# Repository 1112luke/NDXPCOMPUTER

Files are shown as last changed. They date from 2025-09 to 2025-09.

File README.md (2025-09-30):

<h1 align="center">⚡️🚀Notre Dame Rocketry Flight Computer🖥️⚡️</h1>

<h2 align="center">F.E.R.B (For Every Rocketry Build) 🤓</h2>

<p align="center">
  
</p>

<h4 align="center">This is the repository for the HARDWARE DESIGN ONLY. Software for the computer can be found <a href="https://github.com/1112luke/NDXP_COMPUTER_SOFTWARE">here</a></h4>

<p align="center">
  
  
</p>

## Introduction

While initially designed and developed for NDXP, all vehicle applications were heavily considered during the process. The result is a computer that is <i>intended</i> to be used for any and all rocketry vehicles!

## Contributing
This repository is open at all times to any member submitting a Pull Request and merging their code directly into the main branch after approval! If you don't know what a Pull Request is, or if this is your first time using github, it is recommended that you watch [this](https://docs.github.com/en/get-started/start-your-journey/hello-world) guide before you begin.

### Requirements
Before you do anything, make sure you:
 - Have [git](https://git-scm.com/downloads) installed on your computer (macos should by default).
 - Have [kicad](https://www.kicad.org/) installed on your computer
 - Are added as a repository contributor (ask a team lead)

To make a contribution, the generall process is:

<b><i>clone/pull → branch → make your changes → add;commit;push → request approval for merge</i></b>

Each step is broken down as follows:

### Clone/Pull 🤖
If this is your first time interacting with this repository on your local machine, execute the following command in the location on your computer you wish to clone the repository to:

```
git clone https://github.com/1112luke/CubeFlightComputer
```

If you have the repository already and wish to begin a new contribution <b><u>it is important that you get the most recent version of the repository: </u></b>

```
git switch main
git pull origin main --rebase
```

### Branch 🪾
Once you have an up to date copy of the repository on your local machine, you will need to create a new branch for your contribution:

```
git branch -c branch-name
```

```
git switch branch-name
```

Feel free to name it whatever you want. Be descriptive!

### Make Your Changes 👨‍💻
At this point, you are free to make whatever changes you want! Any time you are working in your local copy, you do not have to worry about messing up the project. Feel free to delete the entire thing if you want!
 - Experiment
 - Break Things
 - Absolutely Cook 👨‍🍳

<b>THIS IS HOW WE LEARN!!</b>

### Add;Commit;Push 💡
When you are satisfied with your contribution, execute the following steps to push your changes to github for review:

```
git add .
```

```
git commit -m "your-descriptive-message"
```

```
git push origin branch-name
```

Once that is done, your code should be pushed to this repository! The final step is to submit a pull request for your code to the main branch using this website, and it will be reviewed for merge shortly!

### RULE OF THUMB!!
In general, commits to github should be <b>small</b> and <b>frequent</b>! This ensures that everybody is working with the most up to date version of the code!

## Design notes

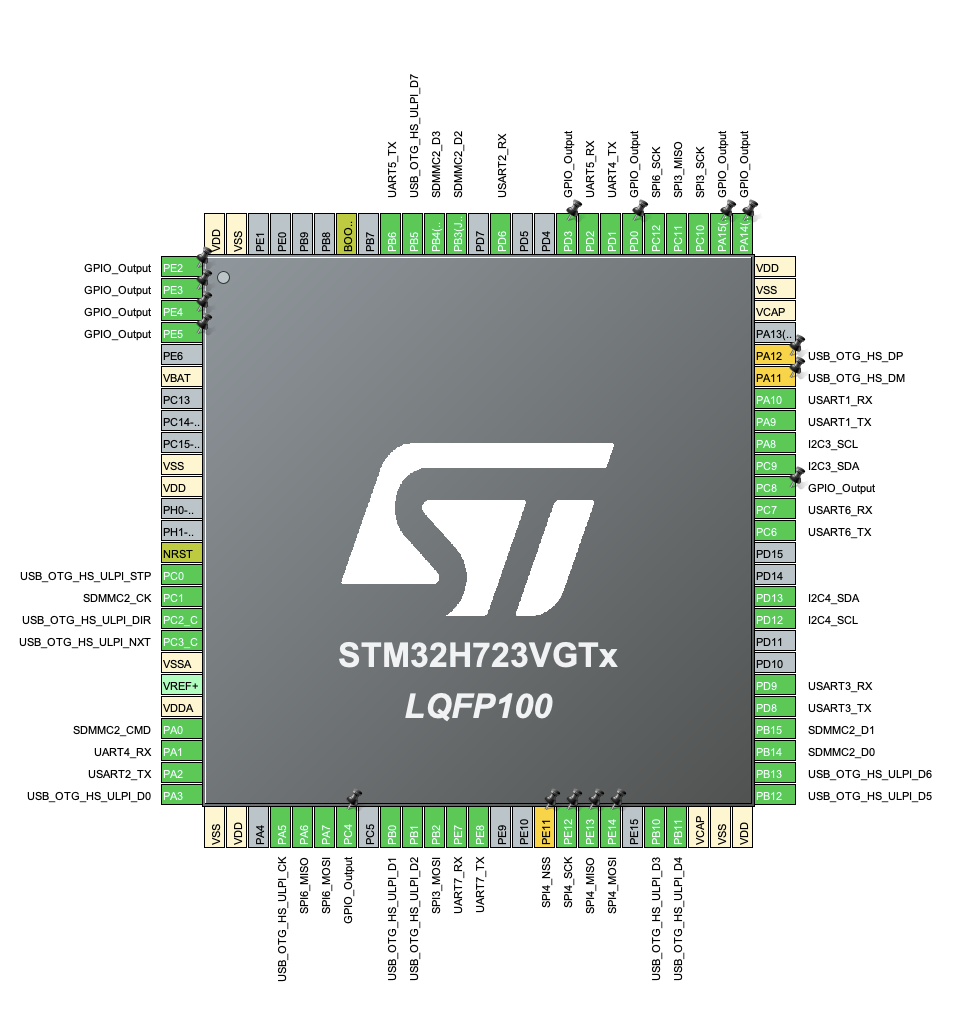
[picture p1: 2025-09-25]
Compute-Comms/Images/Screenshot 2025-09-24 at 10.30.06 PM.png

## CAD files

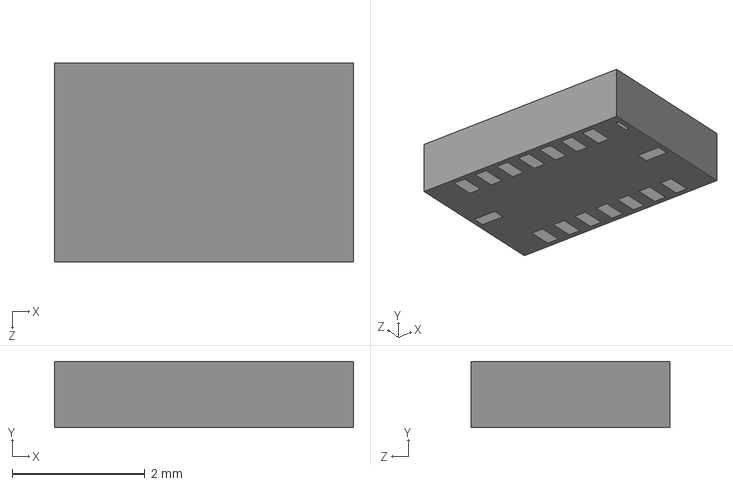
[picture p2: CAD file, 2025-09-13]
Compute-Comms/Custom_Parts/BMI088/BMI088.step
4.50 x 1.00 x 3.00 mm

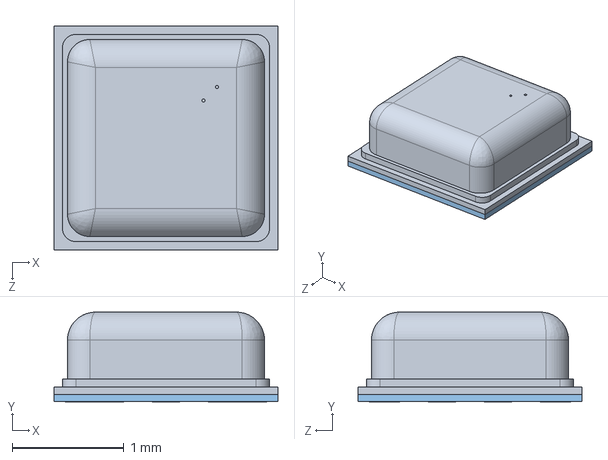
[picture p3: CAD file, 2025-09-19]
Compute-Comms/Custom_Parts/BMP581/BMP581.step
2.00 x 0.801 x 2.00 mm

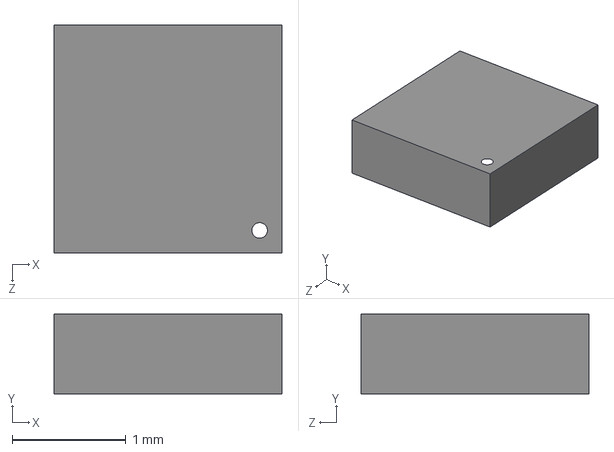
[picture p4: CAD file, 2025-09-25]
Compute-Comms/Custom_Parts/IIS2MDCTR/IIS2MDCTR.step
2.00 x 0.7 x 2.00 mm

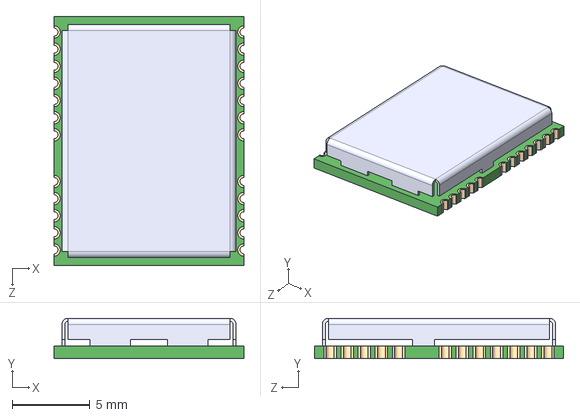
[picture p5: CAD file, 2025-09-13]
Compute-Comms/Custom_Parts/NEO-M9N/NEO-M9N-00B.step
12.2 x 2.60 x 16.0 mm

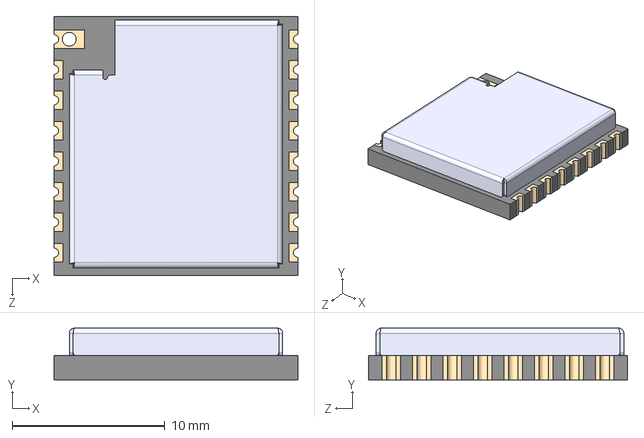
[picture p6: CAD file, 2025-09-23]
Compute-Comms/Custom_Parts/RA-01/RA-01H--3DModel-STEP-1.STEP
16.0 x 3.40 x 17.0 mm

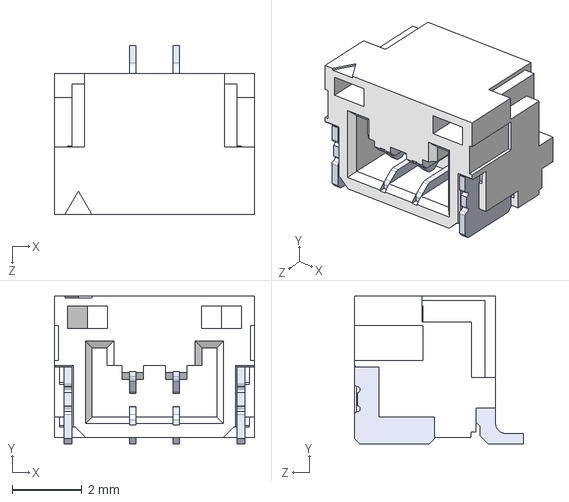
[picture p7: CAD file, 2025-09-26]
Compute-Comms/Custom_Parts/SM02B-GHS/SM02B-GHS.step
5.75 x 4.25 x 4.85 mm
SMxB-GHS-TB_02
pin x 2

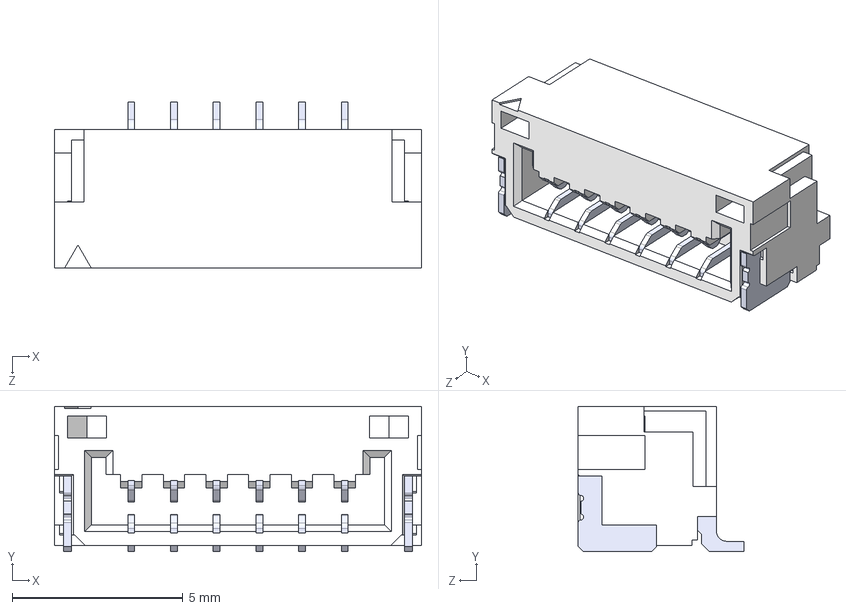
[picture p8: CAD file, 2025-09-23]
Compute-Comms/Custom_Parts/SM06B-GHS-TB/SM06B-GHS-TB_LF__SN_.step
10.8 x 4.25 x 4.85 mm
SMxB-GHS-TB_06
pin x 6

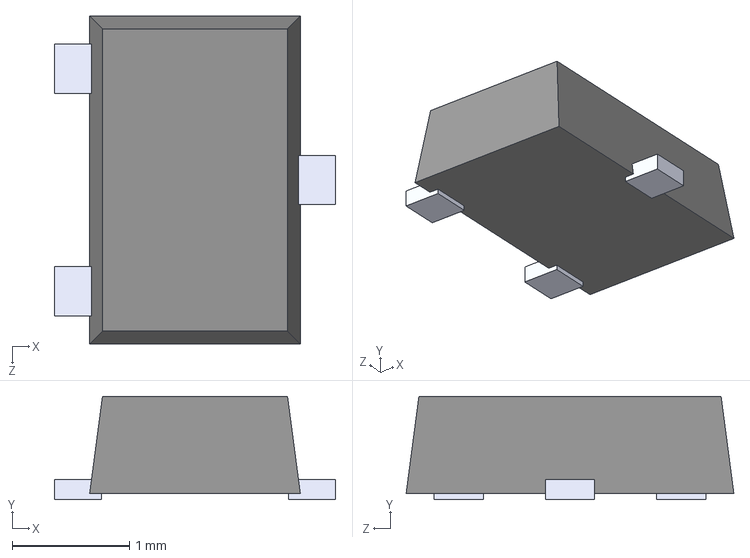
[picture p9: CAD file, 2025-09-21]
Compute-Comms/Custom_Parts/SSM3J328R/SSM3J328R_LF.step
2.40 x 0.88 x 2.80 mm

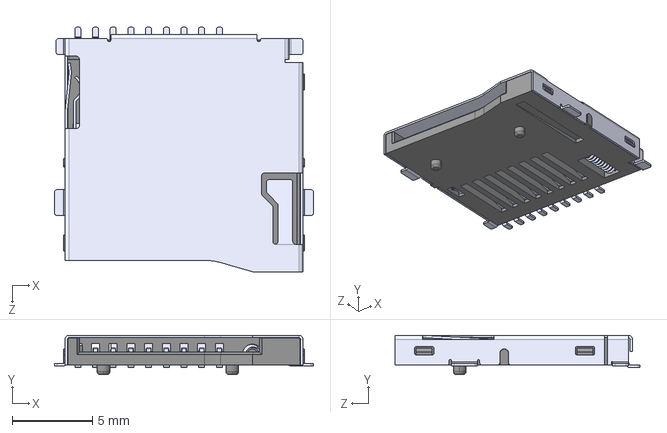
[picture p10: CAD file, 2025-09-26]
Compute-Comms/Custom_Parts/TF-01A/TF-01A.step
16.1 x 2.45 x 15.2 mm

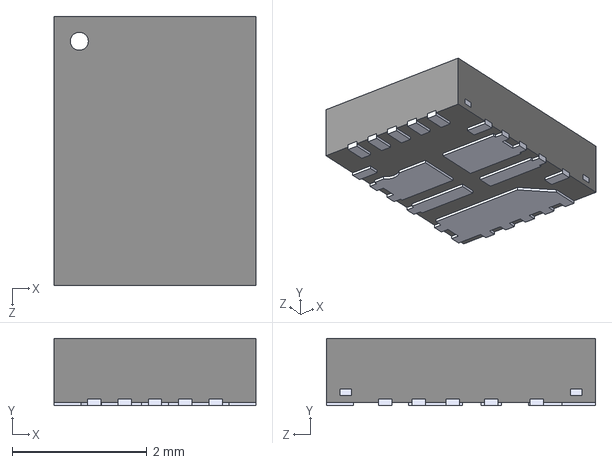
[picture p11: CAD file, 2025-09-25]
Compute-Comms/Custom_Parts/TPS513885VABR/TPS513885VABR.step
3.00 x 1.00 x 4.00 mm

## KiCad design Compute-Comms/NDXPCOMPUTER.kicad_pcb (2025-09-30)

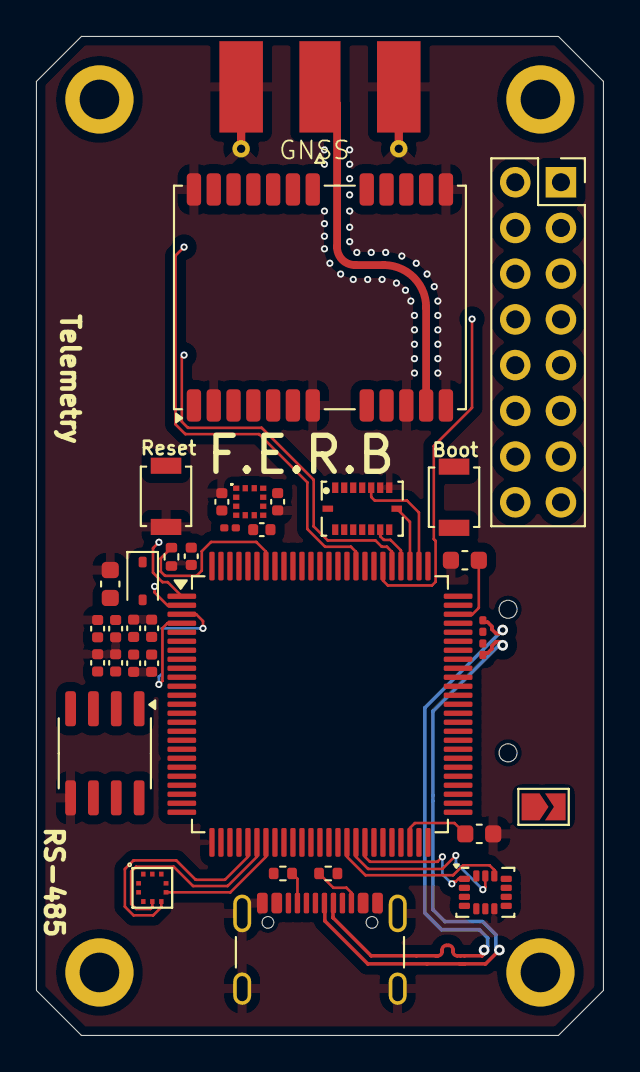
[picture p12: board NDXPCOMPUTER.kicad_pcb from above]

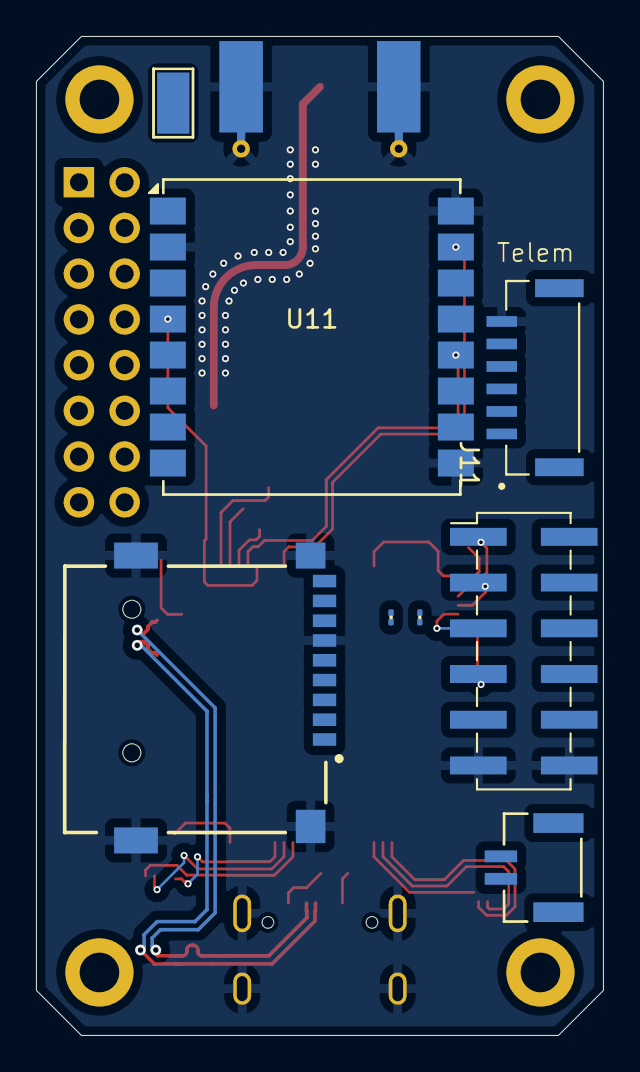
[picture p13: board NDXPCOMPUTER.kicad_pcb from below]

Board: 4 copper layers, 31.5 x 55.5 mm, 47 parts (8 on the bottom side), 44 nets.

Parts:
C1: 0.1uF; C_0402_1005Metric
C2, C3, C4, C5, C6, C7, C8, C9, C29, C30: 100nF; C_0402_1005Metric
C10: 4.7uF; C_0603_1608Metric
C11, C12: 2.2uF; C_0603_1608Metric
C17: 220nF; C_0402_1005Metric
C31: 10uF; C_0201_0603Metric
D1: D; D_SOD-323
D2, D3: LED; LED_01005_0402Metric
H1, H2, H3, H4: MountingHole; MountingHole_2.2mm_M2_DIN965_Pad
IC1: IIS2MDCTR
J2: USB_C_Receptacle_USB2.0_16P; USB_C_Receptacle_GCT_USB4105-xx-A_16P_TopMnt_Horizontal
J3: Conn_Coaxial; SMA_Molex_73251-1153_EdgeMount_Horizontal
J4: Conn_01x02; CONN_SM02B-GHS_JST
J9: Conn_01x01; TestPoint_Keystone_5015_Micro-Minature
J11: Conn_01x06; JST_SM06B-GHS-TB_LF__SN_
J12: Conn_02x08_Counter_Clockwise; PinSocket_2x08_P2.54mm_Vertical
J13: Conn_02x06_Odd_Even; PinHeader_2x06_P2.54mm_Vertical_SMD
JP1: SolderJumper_2_Open; SolderJumper-2_P1.3mm_Open_TrianglePad1.0x1.5mm
MICRO_SD1: TF-01A
R1, R2: 5.1k; R_0402_1005Metric
R3: 10k; R_0402_1005Metric
R6, R7: 22; R_0201_0603Metric
SW1, SW2: SW_Push; SW_SPST_B3U-1000P
U1: STM32H723VGTx; LQFP-100_14x14mm_P0.5mm
U2: BMI088; PQFN50P450X300X100-16N
U3: LSM6DSM; LGA-14_3x2.5mm_P0.5mm_LayoutBorder3x4y
U4: BMP581
U5: NEO-M9N; ublox_NEO
U10: SP3485EN; SOIC-8_3.9x4.9mm_P1.27mm
U11: Ai-Thinker-Ra-01; Ai-Thinker-Ra-01-LoRa

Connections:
+3.3V: C2.1, C3.1, C4.1, C5.1, C6.1, C7.1, C8.1, C9.1, C10.1, C29.1, C30.1, C31.1, IC1.3 (CS), IC1.9 (VDD), IC1.10 (VDD_IO), J13.9, SW1.1, U1.6 (VBAT), U1.11 (VDD), U1.20 (VREF+), U1.21 (VDDA), U1.27 (VDD), U1.50 (VDD), U1.75 (VDD), U1.100 (VDD), U2.3 (VDD), U2.11 (VDDIO), U3.5 (VDDIO), U3.8 (VDD), U4.1 (VDDIO), U4.10 (VDD), U5.22 (V_BCKP), U5.23 (VCC), U10.8 (VCC), U11.3 (VDD)
+5V: J11.1, J13.10
/BMI088/CS_ACCEL: U1.76 (PA14(JTCK), U2.14 (CSB1)
/BMI088/CS_GYRO: U1.77 (PA15(JTDI)), U2.5 (CSB2)
/BMI088/SCK: U1.78 (PC10), U2.8 (SCL/SCK)
/BMI088/SDI: U1.36 (PB2), U2.9 (SDA/SDI)
/BMI088/SDO_ACCEL: U1.79 (PC11), U2.10 (SDO2), U2.15 (SDO1)
/BMM350/SCL_MAG: IC1.1 (SCL/SPC), U1.59 (PD12)
/BMM350/SDA_MAG: IC1.4 (SDA/SDI/SDO), U1.60 (PD13)
/BMP581/CS_BARO: U1.32 (PC4), U4.6 (CSB)
/BMP581/SCK_BARO: U1.80 (PC12), U4.2 (SCK/SCL), U11.12 (SCK)
/BMP581/SDI_BARO: U1.31 (PA7), U4.4 (SDI/SDA), U11.14 (MOSI)
/BMP581/SDO_BARO: U1.30 (PA6), U4.5 (SDO/ADR), U11.13 (MISO)
/LSM6DSM/CS_IMU_LOW: U1.41 (PE11), U3.12 (CS)
/LSM6DSM/SCL_IMU_LOW: U1.42 (PE12), U3.13 (SCL)
/LSM6DSM/SDI_IMU_LOW: U1.44 (PE14), U3.14 (SDA)
/LSM6DSM/SDO_IMU_LOW: U1.43 (PE13), U3.1 (SDO/SA0)
/LoRa/CS_LORA: U1.84 (PD3), U11.15 (~NSS)
/LoRa/RST_LORA: U1.81 (PD0), U11.4 (~RESET)
/Peripherals/PYRO_1: J13.1, U1.1 (PE2)
/Peripherals/PYRO_2: J13.3, U1.2 (PE3)
/Peripherals/PYRO_3: J13.5, U1.3 (PE4)
/Peripherals/PYRO_4: J13.7, U1.4 (PE5)
/RS485/DIR_RS485: U1.65 (PC8), U10.2 (~RE), U10.3 (DE)
/RS485/RX_RS485: U1.64 (PC7), U10.1 (RO)
/RS485/TX_RS485: U1.63 (PC6), U10.4 (DI)
D+: J2.A6 (D+), J2.B6 (D+), R7.2
D-: J2.A7 (D-), J2.B7 (D-), R6.2
GND: C1.2, C2.2, C3.2, C4.2, C5.2, C6.2, C7.2, C8.2, C9.2, C10.2, C11.1, C12.1, C17.2, C29.2, C30.2, C31.2, IC1.6 (GND_1), IC1.8 (GND_2), J2.A1 (GND), J2.A12 (GND), J2.B1 (GND), J2.B12 (GND), J2.S1 (SHIELD), J3.2 (Ext), J11.6, J13.11, J13.12, MICRO_SD1.6 (VSS), MICRO_SD1.MP1 (SHIELD), MICRO_SD1.MP2 (SHIELD), MICRO_SD1.MP3 (SHIELD), MICRO_SD1.MP4 (SHIELD), R1.1, R2.2, R3.2, SW2.1, U1.10 (VSS), U1.12 (PH0), U1.19 (VSSA), U1.26 (VSS), U1.49 (VSS), U1.74 (VSS), U1.99 (VSS), U2.2 (NC), U2.4 (GNDA), U2.6 (GNDIO), U2.7 (PS), U3.2 (SDX), U3.3 (SCX), U3.6 (GND), U3.7 (GND), U4.3 (GND), U4.8 (GND), U4.9 (GND), U5.2 (D_SEL), U5.7 (VDD_USB), U5.10 (GND), U5.12 (GND), U5.13 (GND), U5.24 (GND), U10.5 (GND), U11.2 (GND), U11.9 (GND), U11.16 (GND)
unnamed: C11.2, U1.48 (VCAP)
unnamed: C12.2, U1.73 (VCAP)
unnamed: D1.2 (A), J2.A4 (VBUS), J2.A9 (VBUS), J2.B4 (VBUS), J2.B9 (VBUS)
unnamed: C17.1, IC1.5 (C1)
unnamed: J2.A5 (CC1), R1.2
unnamed: J2.B5 (CC2), R2.1
unnamed: J3.1 (In), U5.11 (RF_IN)
unnamed: J4.1, U10.6 (A)
unnamed: J4.2, U10.7 (B)
unnamed: J9.1, U11.1 (ANT)
unnamed: C1.1, JP1.1 (A), SW2.2
unnamed: JP1.2 (B), U1.14 (NRST)
unnamed: R3.1, SW1.2, U1.94 (BOOT0)
unnamed: R6.1, U1.70 (PA11)
unnamed: R7.1, U1.71 (PA12)

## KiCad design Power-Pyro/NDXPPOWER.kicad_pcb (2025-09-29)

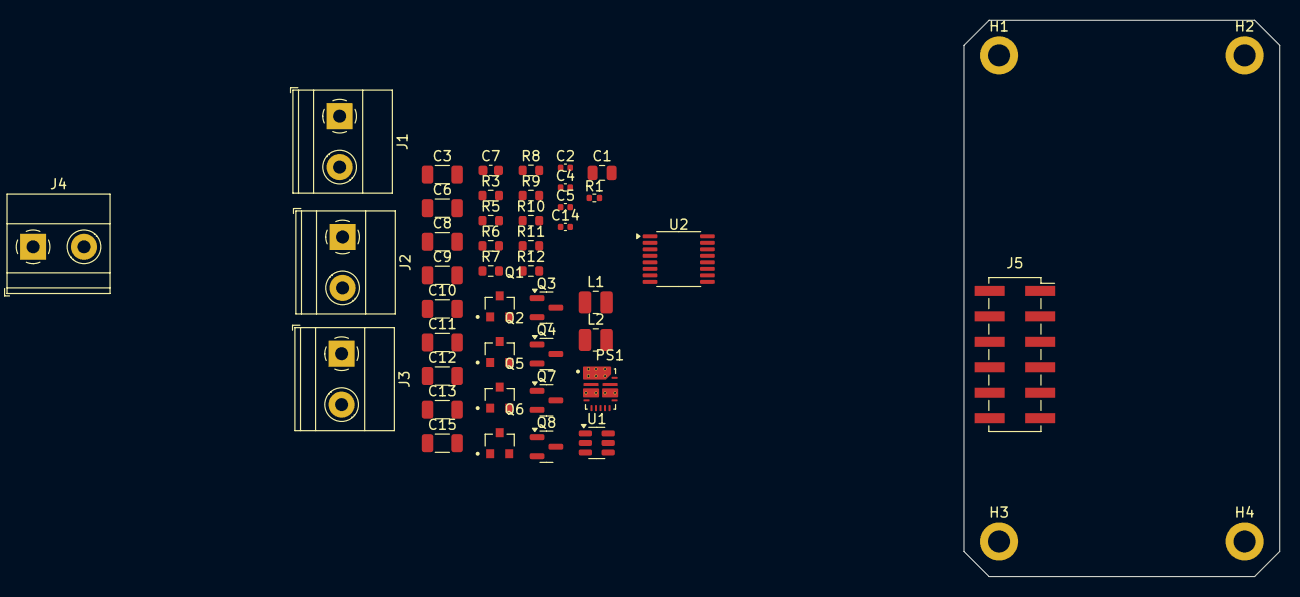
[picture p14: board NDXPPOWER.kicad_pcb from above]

Board: 2 copper layers, 31.5 x 55.5 mm, 47 parts (0 on the bottom side), 27 nets, no tracks yet.

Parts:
C1: 10uF; C_0805_2012Metric
C2: 470pF; C_0402_1005Metric
C3, C6, C8, C9, C10, C11, C12, C13, C15: 22uF; C_1206_3216Metric
C4, C5, C14: 100nF; C_0402_1005Metric
C7: 2.2uF; C_0603_1608Metric
H1, H2, H3, H4: MountingHole; MountingHole_2.2mm_M2_DIN965_Pad
J1, J2, J3, J4: Conn_01x02; TerminalBlock_Phoenix_MKDS-1,5-2-5.08_1x02_P5.08mm_Horizont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
J5: Conn_02x06_Odd_Even; PinSocket_2x06_P2.54mm_Vertical_SMD
L1: 4.7uH; L_1008_2520Metric
L2: 1.5uH; L_1008_2520Metric
PS1: TPS513885VABR; CONV_TPS513885VABR
Q1, Q2, Q5, Q6: SSM3J328R; SOT95P240X88-3N
Q3, Q4, Q7, Q8: L2N7002SLLT1G; SOT-23
R1: 1k; R_0402_1005Metric
R3, R5, R6, R7, R8, R9, R10, R11, R12: 100k; R_0603_1608Metric
U1: AP63203WU; TSOT-23-6
U2: INA260; TSSOP-16_4.4x5mm_P0.65mm

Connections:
+3.3V: C3.1, C6.1, J5.9, L1.2, PS1.5 (MODE), PS1.6 (EN), U1.1 (FB)
+5V: C9.1, C11.1, C13.1, C15.1, J5.10, L2.2
+BATT: C1.1, C8.1, C10.1, C12.1, C14.1, PS1.1 (VIN), Q1.3 (S), Q2.3 (S), Q5.3 (S), Q6.3 (S), R5.1, R6.1, R9.1, R10.1, U1.2 (EN), U1.3 (IN)
FB: C2.1, C9.2, C11.2, C13.2, C15.2, PS1.8 (VOUT)
GND: C1.2, C3.2, C6.2, C7.1, C8.2, C10.2, C12.2, C14.2, J1.1, J2.1, J3.1, J4.1, J5.11, J5.12, PS1.3 (PGND), PS1.11 (PGND), Q3.3 (S), Q4.3 (S), Q7.3 (S), Q8.3 (S), U1.4 (GND)
unnamed: C2.2, R1.1
unnamed: C5.2, L2.1, PS1.2 (SW), PS1.12 (SW)
unnamed: J1.2, Q1.1 (D)
unnamed: J2.2, Q2.1 (D)
unnamed: J3.2, Q5.1 (D)
unnamed: J4.2, Q6.1 (D)
unnamed: PS1.7 (FB), R1.2
unnamed: PS1.4 (PG), R3.1
unnamed: C7.2, PS1.10 (VCC), R3.2
unnamed: Q1.2 (G), R5.2, R7.1
unnamed: Q2.2 (G), R6.2, R8.1
unnamed: Q3.1 (D), R7.2
unnamed: Q4.1 (D), R8.2
unnamed: Q5.2 (G), R9.2, R11.1
unnamed: Q6.2 (G), R10.2, R12.1
unnamed: Q7.1 (D), R11.2
unnamed: Q8.1 (D), R12.2
unnamed: C4.2, U1.6 (BST)
unnamed: C4.1, L1.1, U1.5 (SW)
unnamed: U2.6 (GND), U2.11 (GND)
unnamed: U2.1 (IN+), U2.2 (IN+), U2.3 (IN+)
unnamed: U2.14 (IN-), U2.15 (IN-), U2.16 (IN-)

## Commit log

2025-09-13 computer🤓
    [BMI088.kicad_sch, BMP280.kicad_sch, LSM6DSM.kicad_sch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]
2025-09-13 sensors📡
    [BMI088.kicad_sch, BMI088.step, BMP280.kicad_sch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]
2025-09-14 board🏄‍♂️
    [BMI088.kicad_sch, NDXPCOMPUTER.kicad_pcb, NDXPCOMPUTER.kicad_sch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]
2025-09-14 ignore😴
2025-09-14 move🛝
    [BMI088.kicad_sch, NDXPCOMPUTER.kicad_sch]
2025-09-14 idk what this was
    [NDXPCOMPUTER.kicad_pcb]
2025-09-14 power docs⚡️
    [power.kicad_sch]
2025-09-15 usb-c🔌
    [BMP280.kicad_sch, STM32H7.kicad_sch, power.kicad_sch]
2025-09-16 mcu⚡️
    [NDXPCOMPUTER.kicad_pcb, STM32H7.kicad_sch, power.kicad_sch]
2025-09-16 gps🌎
    [NDXPCOMPUTER.kicad_pcb, NDXPCOMPUTER.kicad_sch, NEO-M9N.kicad_sch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]
2025-09-19 Magnetometer🧲
    [BGA9_BMM350_BOS.step, BMM350.kicad_sch, BMP280.kicad_sch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]
2025-09-19 magnetic🧲
    [BGA9_BMM350_BOS.step, BMM350.kicad_sch, NDXPCOMPUTER.kicad_sch]
2025-09-20 5v⚡️
    [NDXPCOMPUTER.kicad_sch, Peripherals.kicad_sch, power.kicad_sch]
2025-09-21 FETS🦈
    [BMM350.kicad_sch, Peripherals.kicad_sch, SSM3J328R_LF.step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]
2025-09-23 memory🧠
2025-09-23 touchups💅
    [LoRa.kicad_sch, NDXPCOMPUTER.kicad_pcb]
2025-09-23 LoRa🌊
    [Peripherals.kicad_sch, RA-01H--3DModel-STEP-1.STEP, SM06B-GHS-TB_LF__SN_.step]
2025-09-23 routed🛣️
    [BMM350.kicad_sch, BMP280.kicad_sch, LSM6DSM.kicad_sch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]
2025-09-25 rework🗂️
    [BMI088.kicad_sch, BMI088.step, BMM350.kicad_sch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]
2025-09-25 power🔋
    [BMI088.step, BMP581.step, IIS2MDCTR.step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]
2025-09-25 refactor🧮
    [BMI088.step, BMM350.kicad_sch, BMP581.step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]
2025-09-25 separate⚮
    [NDXPCOMPUTER.kicad_sch, Peripherals.kicad_sch, STM32H7.kicad_sch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]
2025-09-25 terminal🚉
2025-09-25 sd♠️
    [NDXPCOMPUTER.kicad_pcb, NDXPCOMPUTER.kicad_sch, NDXPPOWER.kicad_pcb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]
2025-09-25 refactor✖️
    [3.3vREG.kicad_sch, 5vREG.kicad_sch, CurrentSense.kicad_sch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]
2025-09-26 FERBBBB🟣
    [LoRa.kicad_sch, NDXPCOMPUTER.kicad_pcb, NDXPPOWER.kicad_pcb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]
2025-09-26 baller🏀
    [NDXPCOMPUTER.kicad_pcb]
2025-09-26 added current chip
    [3.3vREG.kicad_sch, 5vREG.kicad_sch, CurrentSense.kicad_sch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]
2025-09-30 Diff🍐
    [BMI088.kicad_sch, BMM350.kicad_sch, BMP280.kicad_sch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]
2025-09-30 some⛓️‍💥
    [NDXPCOMPUTER.kicad_pcb]
